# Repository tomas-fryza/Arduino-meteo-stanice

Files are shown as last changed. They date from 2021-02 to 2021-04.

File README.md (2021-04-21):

# Jednoduchá meteo stanice krok za krokem

Cílem tohoto projektu je seznámení s populární platformou Arduino, která obsahuje 8bitový mikrokontrolér AVR a je vhodná pro celou řadu řídicích aplikací. Bude vytvořen jednoduchý bod v síti Internet of Things, konkrétně meteo stanici se senzorem teploty a relativní vlhkosti vzduchu. Pro odesílání dat na server ThingSpeak je použita WiFi komunikace.

# Obsah
* [Použité komponenty](#Použité-komponenty)
* [Blokový diagram aplikace](#Blokový-diagram-aplikace)
* [Arduino Uno](#Arduino-Uno)
* [Sériová komunikace se senzorem a UART](#Sériová-komunikace-se-senzorem-a-UART)
  * [Sběrnice I2C](#Sběrnice-I2C)
  * [Asynchronní komunikace UART](#Asynchronní-komunikace-UART)
  * [Zobrazení dat ze senzoru v Serial monitoru](#Zobrazení-dat-ze-senzoru-v-Serial-monitoru)
* [WiFi komunikace](#WiFi-komunikace)
  * [Server ThingSpeak](#Server-ThingSpeak)
  * [Odeslání dat na server ThingSpeak](#Odeslání-dat-na-server-ThingSpeak)
* [Verze zdrojových kódů](#Verze-zdrojových-kódů)
* [Modifikace stanice](#Modifikace-stanice)
* [Kontakt](#Kontakt)

## Použité komponenty

* Vývojová deska [Arduino Uno](https://arduino-shop.cz/arduino/1353-klon-arduino-uno-r3-atmega328p-ch340-mini-usb-1466635561.html)
* I2C senzor vlhkosti a teploty DHT12 nebo [DHT11](https://dratek.cz/arduino/1360-dht11-dps-vodice-mereni-teploty-a-relativni-vlhkosti-modul-pro-arduino.html): [data sheet DHT12](Docs/dht12_manual.pdf), [návod DHT11](https://navody.dratek.cz/navody-k-produktum/teplotni-senzor-dht11.html)
* WiFi modul [ESP8266](https://dratek.cz/arduino/911-internet-veci-je-tady-tcp-ip-wifi-esp8266-esp-01.html): [AT příkazy](Docs/esp8266_at_instruction_set.pdf)
* [Nepájivé pole](https://dratek.cz/302-nepajive-pole/), propojující [vodiče](https://dratek.cz/arduino/827-vodice-samec-samec-65-kusu.html)
* Prostředí [Arduino IDE](https://www.arduino.cc/en/software) pro Windows, Linux, Mac OS X
* Server [ThingSpeak](https://thingspeak.com/)

Pro ověření komunikace je vhodnou komponentou také:
* 24MHz 8-kanálový [logický analyzátor](https://www.ebay.com/sch/i.html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)
* [Ovládací software](https://www.saleae.com/downloads/) logického analyzátoru pro Windows, Linux, Mac OS X

Obvodová schémata byla vytvořena v programu Fritzing 0.8.7b:
* Verze pro [Windows](http://fritzing.org/download/0.8.7b/windows/fritzing.0.8.7b.pc.zip)
* Verze pro [Linux](http://fritzing.org/download/0.8.7b/linux-32bit/fritzing-0.8.7b.linux.i386.tar.bz2)
* Verze pro [Mac OS](http://fritzing.org/download/0.8.7b/mac-os-x-105/fritzing.0.8.7b.cocoa.dmg)
* Model senzoru [DHT12](https://github.com/Bobadas/DHT12_library_Arduino/blob/master/DHT12%20Fritzing%20component.fzpz)
* Model WiFi modulu [ESP8266-01](https://github.com/ydonnelly/ESP8266_fritzing)

## Blokový diagram aplikace

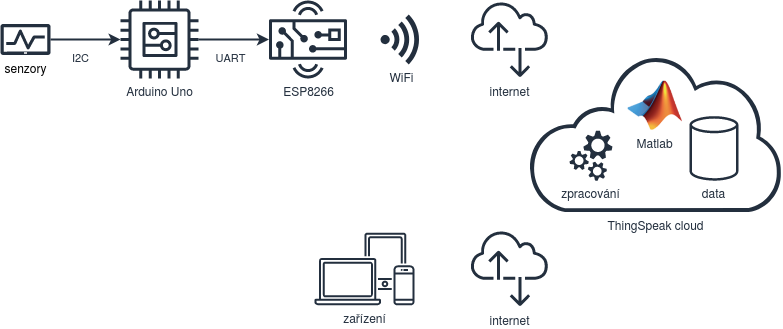
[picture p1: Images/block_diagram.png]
Blokový diagram


## Arduino Uno

Arduino je projekt vyvíjející otevřené platformy založené na 8bitovém mikrokontroléru s architekturou AVR (konkrétně [ATmega328P](https://www.microchip.com/wwwproducts/en/ATmega328P)). Podrobný popis HW modulů, včetně dostupných SW nástrojů, knihoven a manuálů naleznete na [webových stránkách](http://www.arduino.cc). Kromě originálu lze použít i levnější klony, které jsou plně kompatibilní.

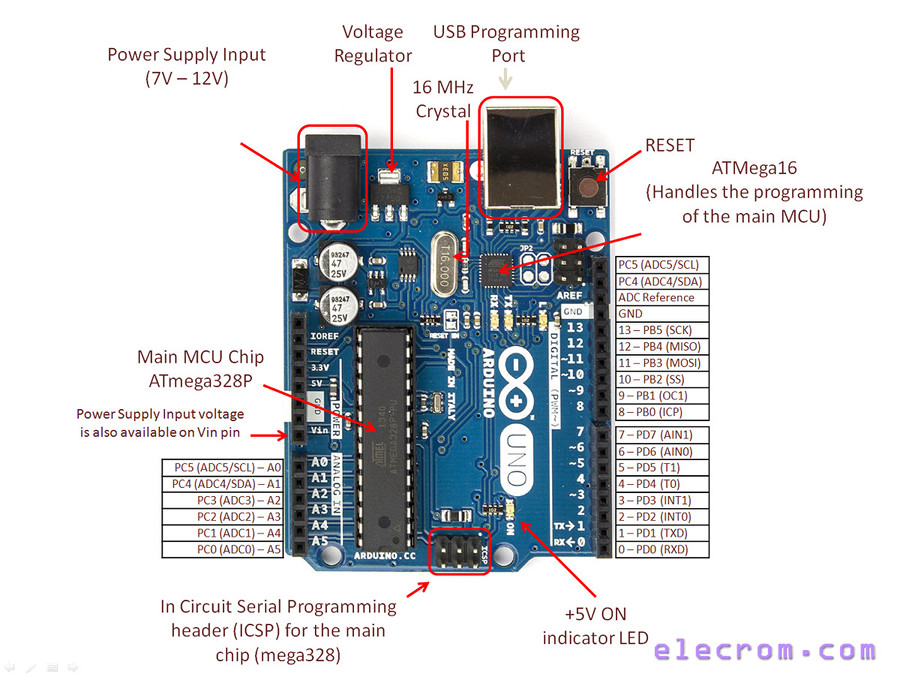
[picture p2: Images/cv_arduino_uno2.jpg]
Vývojová deska Arduino Uno


Řídicí program mikrokontroléru (tzv. firmware) je vyvíjen ve zjednodušené verzi jazyka C++ v prostředí [Arduino](https://www.arduino.cc/en/software), které je zdarma dostupné pro Windows, Mac OS X i Linuxové distribuce. Lze použít online verzi Arduino Web Editor (ke kterému je potřeba doinstalovat Arduino Create Agent pro programování hardwaru) nebo si stáhnout a lokálně nainstalovat prostředí Arduino IDE.

Toto prostředí je velmi jednoduché a kromě textového editoru nabízí jen několik ovládacích prvků. My využijeme pouze: **Verify** pro přeložení zdrojového kódu, **Upload** pro nahrání binární verze kódu do vývojové desky a **Serial Monitor** k otevření nového okna s asynchronní komunikaci mezi mikrokontrolérem a počítačem po USB kabelu.

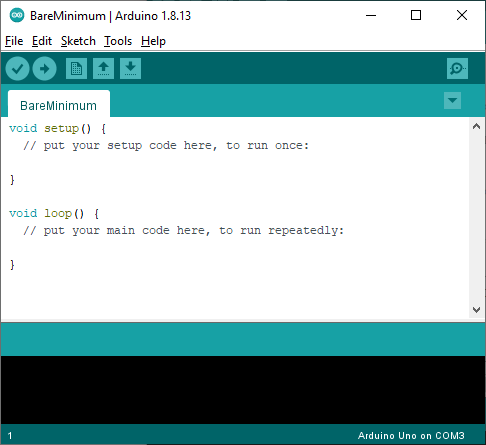
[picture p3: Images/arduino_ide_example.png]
Vývojové prostředí Arduino IDE


## Sériová komunikace se senzorem a UART

### Sběrnice I2C

Pomocí nepájivého pole a vodičů připojte na datový (SDA) a hodinový (SCL) signál sběrnice I2C modul pro měření teploty/vlhkosti DHT12. Pro napájení použijte napětí 3.3 V a GND z vývojové desky Arduina.

   | **DHT12** | **Arduino Uno** |
   | :-: | :-: |
   | + | 3.3V |
   | SDA | SDA |
   | - | GND |
   | SCL | SCL |

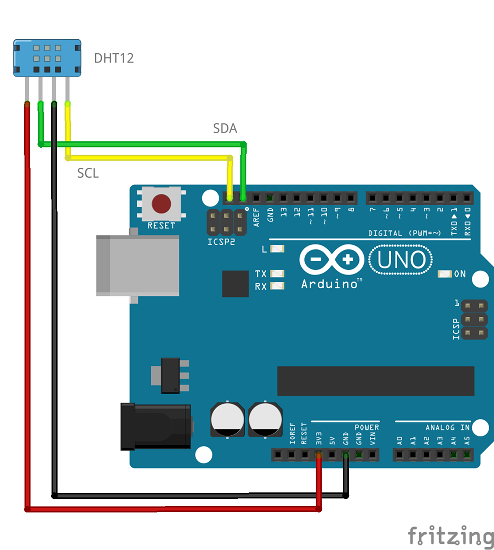
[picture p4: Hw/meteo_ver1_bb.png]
Zapojení senzoru DHT12


Kombinované čidlo komunikuje po digitální sériové sběrnici I2C (Inter-integrated Circuit). Ta obsahuje dva vodiče: pro přenos dat s označením SDA a pro přenos hodinových impulzů SCL a umožňuje snadné propojení jednoho nadřízeného obvodu (tzv. master) s více podřízenými obvody (slave). Jako master je použit mikrokontrolér AVR na vývojové desce Arduino Uno a slave obvod je čidlo teploty/vlhkosti DHT12 (lze ale připojit desítky dalších slave obvodů).

Při komunikaci na sběrnici I2C se nejprve adresuje podřízený obvod jediněčnou adresou, která je zadaná od výrobce (pro obvod DHT12 je to adresa 184 pro zápis a 185 pro čtení). Následně může proběhnout výměna dat jedním nebo druhým směrem.

Vnitřní uložení dat v senzoru DHT12:

   | **Adresa registru** | **Popis** |
   | :-: | :-- |
   | 0 | Celočíselná část vlhkosti |
   | 1 | Desetinná část vlhkosti |
   | 2 | Celočíselná část teploty |
   | 3 | Desetinná část teploty |
   | 4 | Kontrolní součet |

Hodnota relativní vlhkosti vzduchu i teploty se skládá z celočíselné a desetinné části. Pro zjištění obou veličin je tak potřebné přijmout ze senzoru 4 datové byty uložené na vnitřní adrese 0 až 3. Ukázka sériové komunikace I2C pomocí logického analyzátoru; konkrétně byla přenesena hodnota vlhkosti `24.0`% a teploty `22.4` stupňů Celsia:

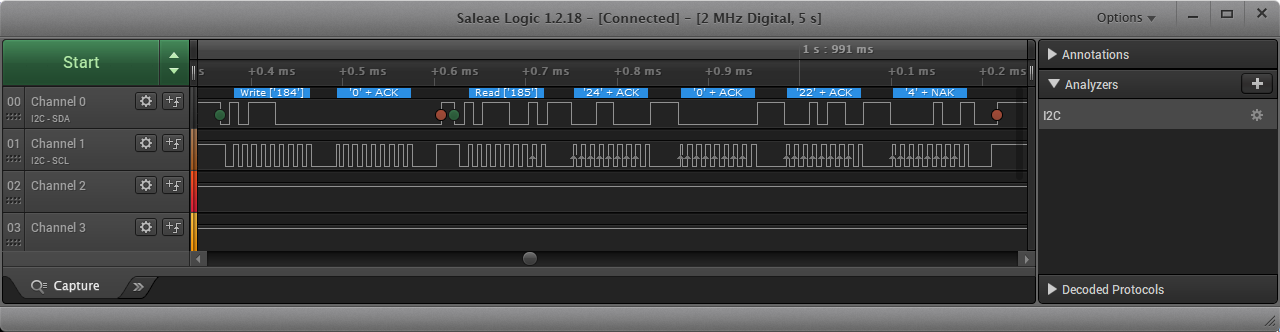
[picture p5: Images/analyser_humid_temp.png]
I2C komunikace se senzorem


Pro ovládání komunikace I2C jsou využity funkce z knihovny [`Wire.h`](https://www.arduino.cc/en/reference/wire). Detailnější informace o sériové komunikaci I2C je možné nalézt v materiálech předmětu [Digitální elektronika 2](https://github.com/tomas-fryza/Digital-electronics-2/tree/master/Labs/08-i2c).

### Asynchronní komunikace UART

Jednotka UART (Universal Asynchronous Receiver Transmiter) umožňuje převádět paralelní data na sériová a opačně. Obsahuje vysílací signál Tx i přijímací Rx a rychlost komunikace se udává v Bd (bódech). Typickou hodnotou je např. 9600 Bd.

Užitečná data jsou zabalena do komunikačního rámce, který začíná start bitem, následuje pět až devět datových bitů seřazených od LSB k MSB, může být použit paritní bit pro základní ověření korektního příjmu (sudá nebo lichá). Komunikace je zakončena jedním nebo dvěma stop bity. Struktura rámce musí být dopředu domluvena a označuje se symbolicky: 7E2 (sedm datových bitů, sudá parita, dva stop bity), 8N1 (osm dat, bez parity, jeden stop), apod.

Ukázka UART komunikace v módu 8N1 pomocí logického analyzátoru:

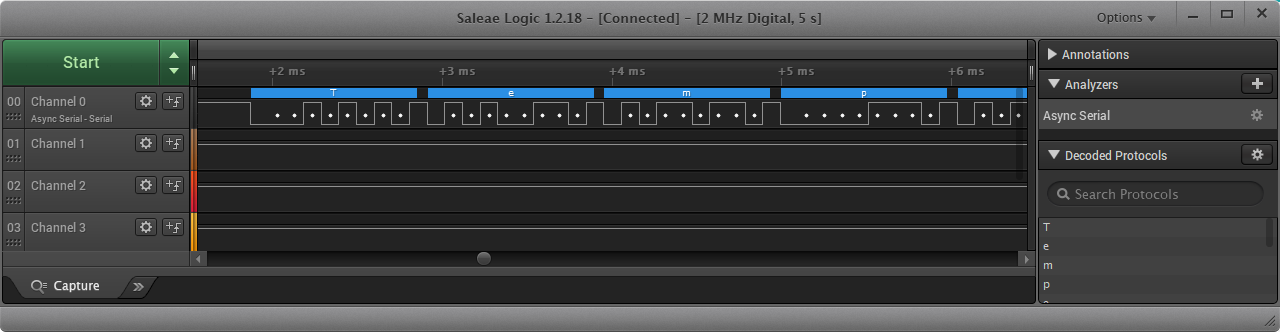
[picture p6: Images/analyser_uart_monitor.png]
Přenos AT příkazu pomocí UART


Pro ovládání sériové komunikace UART jsou využity interní funkce Arduina [`Serial`](https://www.arduino.cc/reference/en/language/functions/communication/serial/). Detailnější informace o sériové komunikaci UART je možné nalézt v materiálech předmětu [Digitální elektronika 2](https://github.com/tomas-fryza/Digital-electronics-2/tree/master/Labs/07-uart).

### Zobrazení dat ze senzoru v Serial monitoru

Zdrojový kód aplikace pro čtení dat ze senzoru a jejich zobrazení v **Sériovém monitoru** překopírujte z [meteo_ver1](https://github.com/tomas-fryza/Arduino-meteo-stanice/blob/main/Arduino/meteo_ver1/meteo_ver1.ino) do Arduino IDE, zkompilujte jej a nahrajte do vývojové desky. Otevřete sériový monitor a nastavte v něm stejnou symbolovou rychlost s jakou mikrokontrolér data vysílá, tj. 9600 baud.

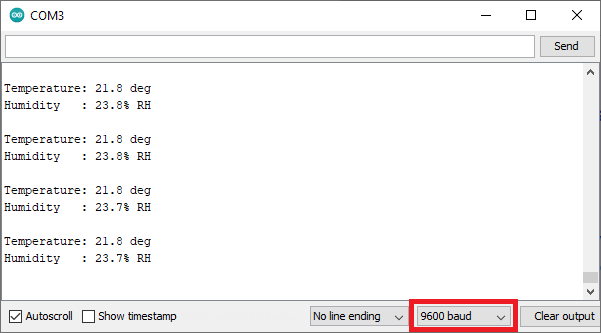
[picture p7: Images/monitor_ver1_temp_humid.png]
Serial monitor


## WiFi komunikace

Komunikační modul ESP8266 umožňuje využít bezdrátovou síť WiFi, připojit se k ní a odesílat data na server. Ovládání modulu probíhá prostřednictvím tzv. [AT příkazu](Docs/esp8266_at_instruction_set.pdf) což jsou textové řetězce začínající znaky `AT` a pokračující příkazem z manuálu.

Pomocí nepájivého pole a vodičů připojte WiFi modul ESP8266 ESP-01 a Arduino Uno dle tabulky. Výměna dat mezi modulem a řídicím mikrokontrolérem probíhá prostřednictvím asynchronní komunikace. Všimněte si, že vysílací pin modulu je proto spojen s přijímacím pinem Arduino a obráceně.

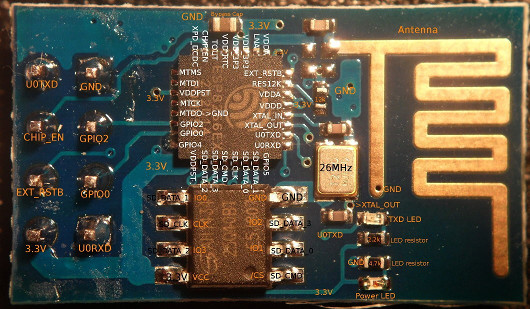
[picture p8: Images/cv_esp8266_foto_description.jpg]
Připojení modulu ESP8266


   | **ESP8266** | **Arduino Uno** |
   | :-: | :-: |
   | U0TXD | Rx (pin 0) |
   | CHIP_EN | 3.3V |
   | EXT_RSTB | Nepřipojeno |
   | 3.3V | 3.3V |
   | GND | GND |
   | GPIO2 | Nepřipojeno |
   | GPIO0 | Nepřipojeno |
   | U0RXD | Tx (pin 1) |

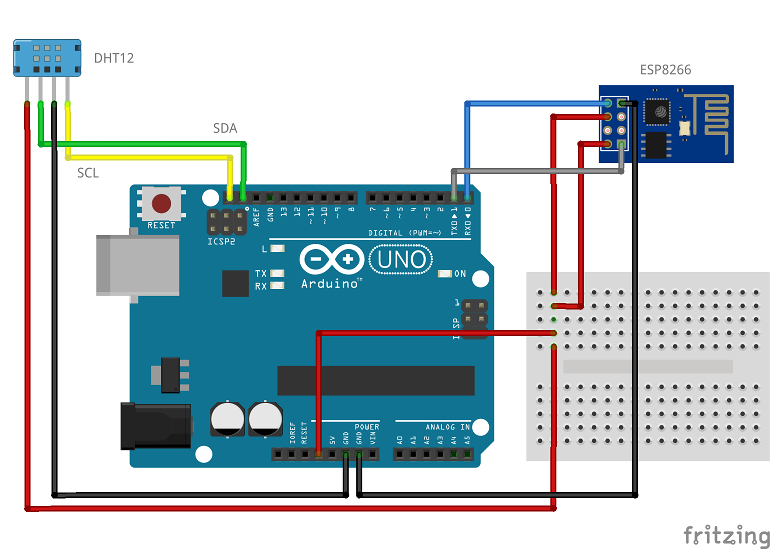
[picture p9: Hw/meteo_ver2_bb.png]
Zapojení modulu ESP8266


### Server ThingSpeak

Pro vytvoření komunikačního kanálu pro sběr dat z vašeho senzoru postupujte podle následujících kroků:

1. V prohlížeči otevřete stránku https://thingspeak.com/ a stiskněte tlačítko **Get Started For Free**.

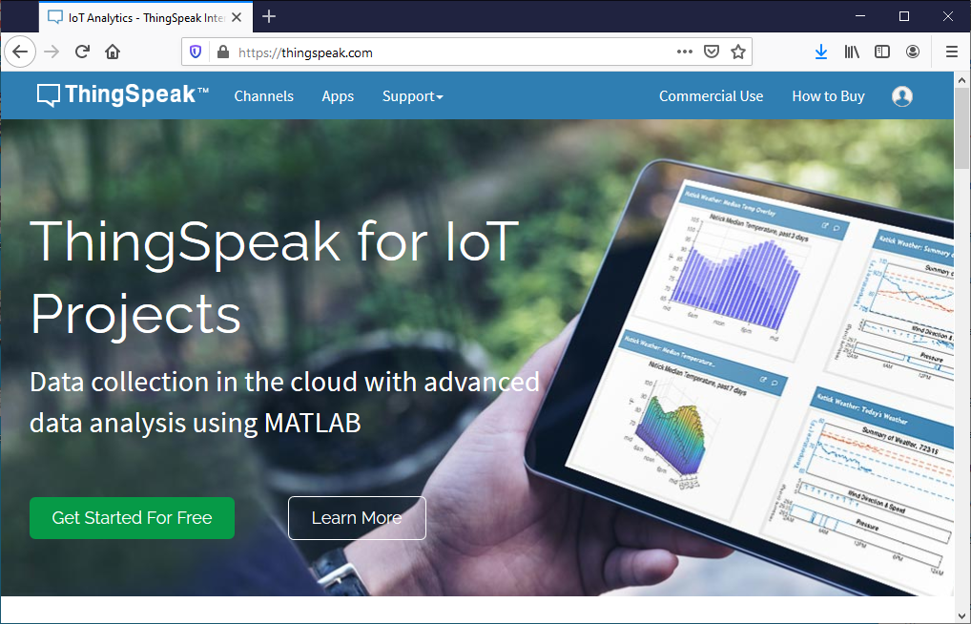
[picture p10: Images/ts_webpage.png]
Web ThingSpeak
   

2. Vytvořte si účet--který je zdarma--pomocí vašeho emailu. Žádnou reklamu na email nerozesílají. Po vytvoření se do systému nalogujte.
3. Vytvořte nový komunikační kanál tlačítkem **New Channel**. Seznam kanálů naleznete kdykoliv v menu **Channels > My Channels**.
4. Vyplňte jméno kanálu, jeho případný popis a vyberte kolik hodnot budete v kanálu posílat. V části **Tags** můžete uvést klíčová slova, podle kterých bude váš kanál lépe dosažitelný. Vše uložte tlačítkem **Save Channel**.

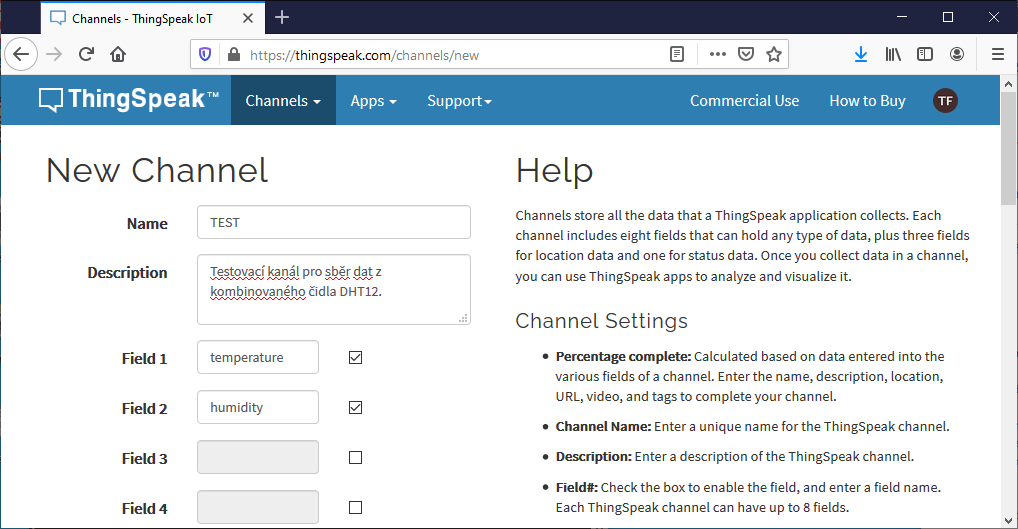
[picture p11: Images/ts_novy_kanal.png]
Tvorba nového kanálu
   

5. Nastavení kanálu můžete kdykoliv změnit a doplnit v záložce **Channel Settings**. Volbou **Sharing** lze nastavit, zda vaše data budou dostupná všem, nebo jen vám po nalogování. V záložce **API Keys** naleznete identifikátory, které byly pro váš kanál vygenerovány a jsou jeho jedinečným označením. V naší aplikaci budeme na server pouze zapisovat a budeme tak potřebovat pouze **Write API Key**, který později vložíme do zdrojového kódu aplikace.

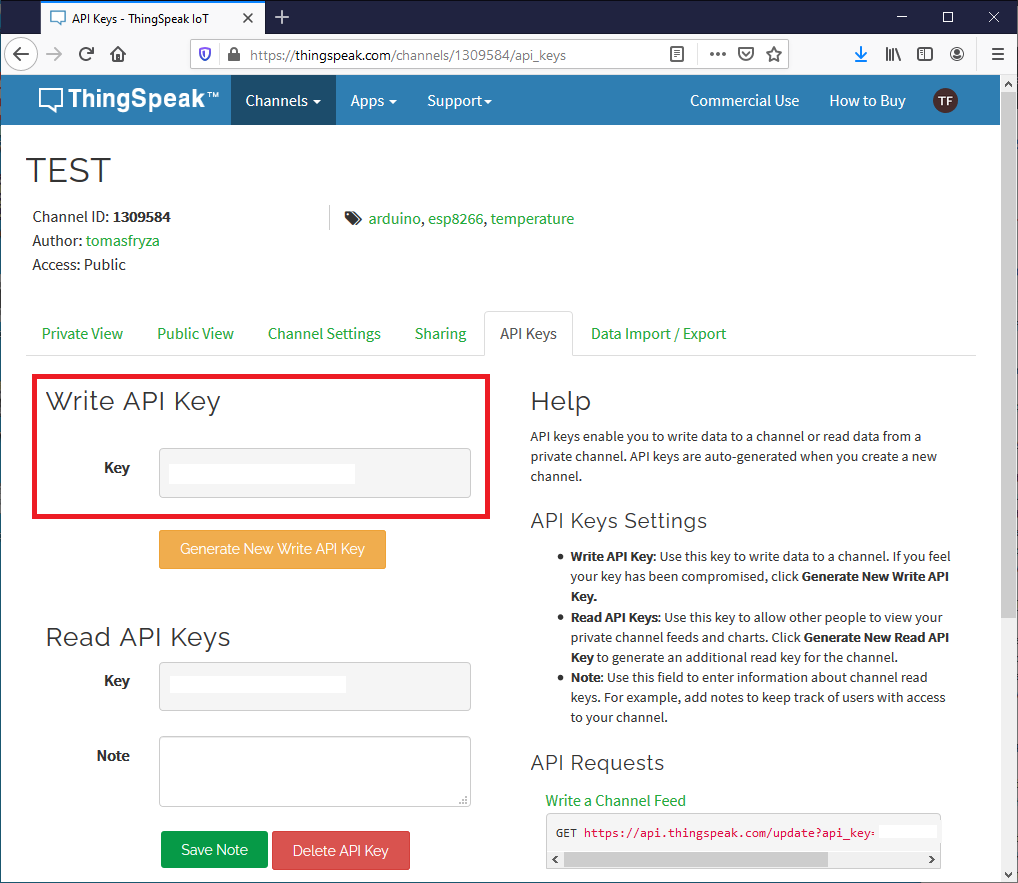
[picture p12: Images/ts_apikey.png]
Write API Key
   

6. Data je možné zobrazit odděleně pro vás (**Private View**) nebo pro všechny ostatní (**Public View**).

### Odeslání dat na server ThingSpeak

Použijte zdrojový kód [meteo_ver2](https://github.com/tomas-fryza/Arduino-meteo-stanice/blob/main/Arduino/meteo_ver2/meteo_ver2.ino) a překopírujte jej do prostředí Arduino IDE. Do kódu doplňte informace o vaší WiFi síti a APIWrite kód z předchozího bodu.

```c
// ENTER YOUR VALUES
String ssid        = "xxx"; // SSID of your WiFi network
String password    = "xxx"; // Password of your WiFi network
String writeApiKey = "xxx"; // Write API Key from ThingSpeak cloud
```

Kód přeložte a nahrajte do Arduino Uno. Vzhledem k tomu, že programování Arduina probíhá na stejných pinech, kde je připojen i WiFi modul, před samotným uploadem kódu odpojte vodiče z pinů 0 a 1 (Rx a Tx). Po úspěšném naprogramování vodiče opět připojte. Spusťte **Serial Monitor** na kterém pozorujte část komunikace s WiFi modulem (pozor, odpovědi modulu se nezobrazují a je nutné nastavit rychlost komunikace na 115200 baud):

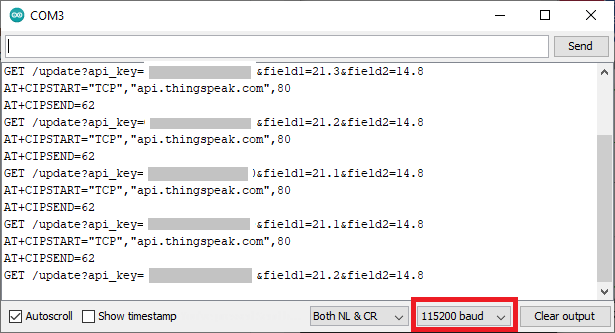
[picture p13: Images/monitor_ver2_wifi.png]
Serial monitor


Je-li komunikace prostřednictvím WiFi sítě korektní, na webové stránce `thingspeak.com` se začnou shromažďovat a zobrazovat změřená data. Pokud tomu tak není, zkontrolujte zadané údaje v kódu, případně si zobrazte asynchronní komunikaci na pinech 0 a 1 pomocí logického analyzátoru.

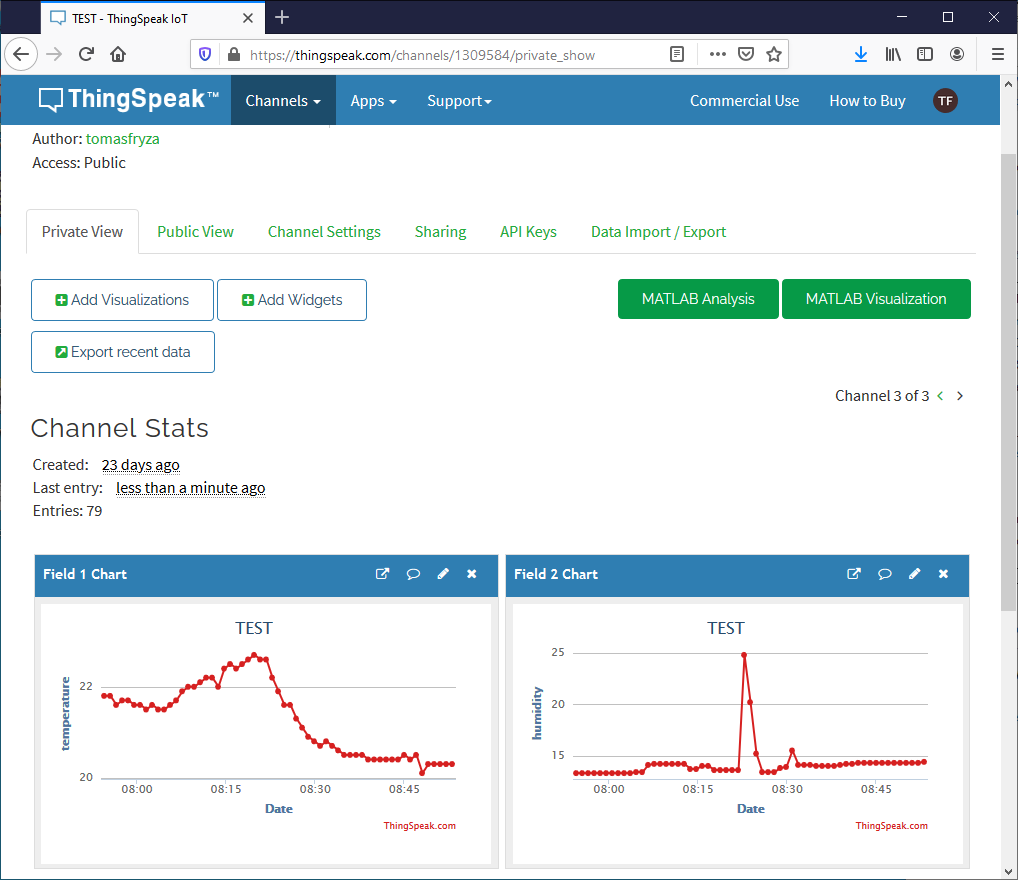
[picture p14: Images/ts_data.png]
Sběr dat na ThingSpeak


## Verze zdrojových kódů

   | **Číslo verze** | **Popis** |
   | :-: | :-- |
   | [ver0](Arduino/meteo_ver0/meteo_ver0.ino) | Skener zařízení připojených na sběrnici I2C |
   | [ver1](Arduino/meteo_ver1/meteo_ver1.ino) | Čtení teploty + vlhkosti z DHT12 a zobrazení v Serial monitoru |
   | [ver2](Arduino/meteo_ver2/meteo_ver2.ino) | Čtení hodnot z DHT12 a odeslání pomocí ESP8266 na ThingSpeak |
   | [ver3](Arduino/meteo_ver3/meteo_ver3.ino) | Komunikace s WiFi modulem ESP8266 pomocí softwarového UARTu  |

## Modifikace stanice

Rozšířit tuto základí aplikaci lze celou řadou modulů a senzorů, např. tlak vzduchu, míra osvětlení, senzor srážek, síla větru, vlhkost půdy, aj. Velký výběr naleznete např. na serveru [dratek.cz](https://dratek.cz/).

Vladimír Lahoda. [Automatizovaný měřící systém pro zavlažování rostlin s IoT konektivitou](https://www.facebook.com/URELBrno/posts/1459331204276701). Bakalářská práce v programu BPC-EKT, červen 2020. Klíčová slova: LoRa, ESP32, Embedded, Meteostanice, Zavlažování.

## Q & A

Q: Kolik dat lze do jednoho kanálu ThingSpeak odeslat?

Q: Jaký je celkový datový tok?

## Kontakt

<!-- Please don't remove this: Grab your social icons from https://github.com/carlsednaoui/gitsocial -->
<!-- display the social media buttons in your README -->



[][2]
[][6]

<!-- links to social media icons -->
<!-- no need to change these -->

<!-- icons with padding -->

[1.1]: http://i.imgur.com/tXSoThF.png (twitter icon with padding)
[2.1]: http://i.imgur.com/P3YfQoD.png (facebook icon with padding)
[3.1]: http://i.imgur.com/yCsTjba.png (google plus icon with padding)
[4.1]: http://i.imgur.com/YckIOms.png (tumblr icon with padding)
[5.1]: http://i.imgur.com/1AGmwO3.png (dribbble icon with padding)
[6.1]: http://i.imgur.com/0o48UoR.png (github icon with padding)

<!-- icons without padding -->

[1.2]: http://i.imgur.com/wWzX9uB.png (twitter icon without padding)
[2.2]: http://i.imgur.com/fep1WsG.png (facebook icon without padding)
[3.2]: http://i.imgur.com/VlgBKQ9.png (google plus icon without padding)
[4.2]: http://i.imgur.com/jDRp47c.png (tumblr icon without padding)
[5.2]: http://i.imgur.com/Vvy3Kru.png (dribbble icon without padding)
[6.2]: http://i.imgur.com/9I6NRUm.png (github icon without padding)

<!-- links to your social media accounts -->
<!-- update these accordingly -->

[1]: http://www.twitter.com/carlsednaoui
[2]: https://www.facebook.com/URELBrno
[3]: https://plus.google.com/+CarlSednaoui
[4]: http://carlsed.tumblr.com
[5]: http://dribbble.com/carlsednaoui
[6]: http://www.github.com/tomas-fryza

<!-- Please don't remove this: Grab your social icons from https://github.com/carlsednaoui/gitsocial -->

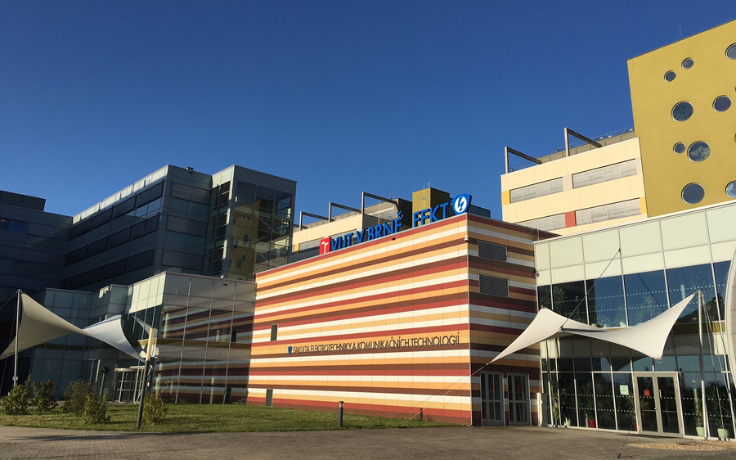
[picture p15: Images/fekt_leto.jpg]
Foto fakulty FEKT


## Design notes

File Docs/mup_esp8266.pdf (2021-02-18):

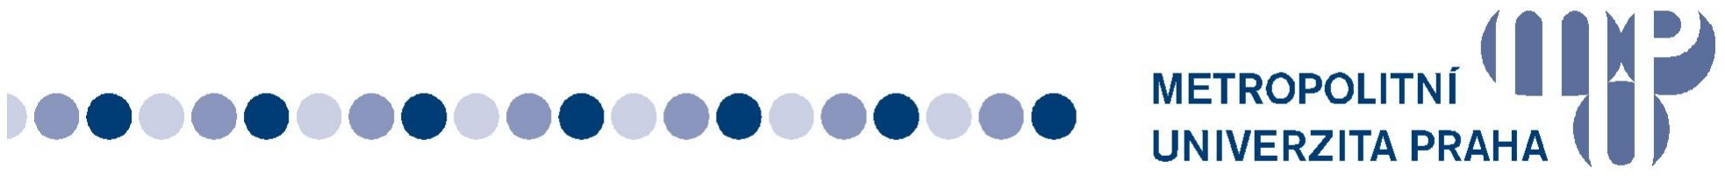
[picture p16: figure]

# Technologicko-experimentální praxe

## Arduino (duben 2018)

doc. Ing. Tomáš Frýza, Ph.D.

Metropolitní univerzita Praha | 1

## Obsah

1 Základní použití platformy Arduino | 4
2 Rízení sériové komunikace I2C ˇ | 11
3 Komunikace s WiFi modulem | 17

2 | Technologicko-experimentální praxe

## Seznam obrázků

1.1 Vývojová deska Arduino Uno | | 4
1.2 Vývojové prostředí Arduino IDE s příkladem Blink | | 5
1.3 Casový průběh signálu LED diody ˇ | | | 6
1.4 Zapojení druhé LED diody prostřednictvím nepájivého pole | | 7
1.5 Průběh časového signálu asynchronní komunikace s dekódovanými daty | | 9
2.1 Zachycení sériové komunikace na sběrnici I2C | | 14
3.1 Označení pinů na modulu ESP8266 ESP-01 | | 18
3.2 Vizualizace měřených dat na serveru https://thingspeak.com/ | | 21

## Seznam tabulek

2.1 Uložení dat v kombinovaném senzoru DHT12 | | 12
2.2 Uložení dat v obvodu reálného času RTC DS3231 | | 14

## 1 Základní použití platformy Arduino

Cílem tohoto cvičení je seznámení s populární platformou Arduino, která obsahuje 8bitový mikrokontrolér AVR a je vhodná pro celou řadu řídicích aplikací. Aplikace budou programovány v jazyce C++ v prostředí Arduino IDE, které je zdarma dostupné pro Windows, Mac OS X i Linux. Pro verifikaci správné funkce aplikací bude použit logický analyzátor firmy Seleae, Inc.

### 1.1 Arduino Uno

Arduino je projekt vyvíjející otevřené platformy založené na 8bitovém mikrokontroléru s architekturou AVR. Podrobný popis HW modulů, včetně dostupných SW nástrojů, knihoven a manuálů naleznete na webových stránkách http://www.arduino.cc. Ve cvičení je využívána základní vývojová deska Arduino Uno, resp. její levnější, ale plně kompatibilní čínský klon.

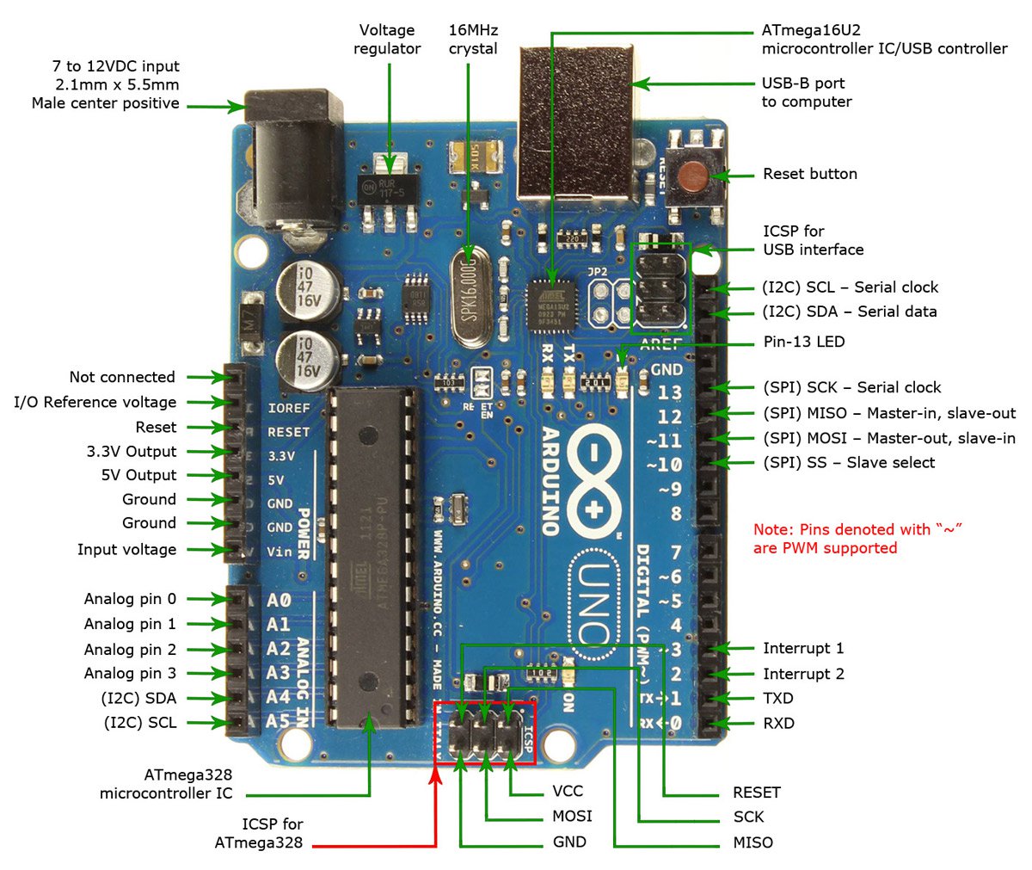
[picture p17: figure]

Obrázek 1.1: Vývojová deska Arduino Uno

Vývojové prostředí Arduino IDE je velmi jednoduché a kromě textového editoru nabízí několik ovládacích prvků. My využijeme pouze: Verify (Compile) pro přeložení zdrojového kódu, Upload pro nahrání binární verze kódu do vývojové desky a Serial Monitor k otevření nového okna s asynchronní komunikaci mezi mikrokontrolérem a počítačem po USB kabelu.

Příklad 1.1. Naprogramujte aplikaci pro blikání jedné LED diody.

Rešení 1.1. ˇ | Prostředí obsahuje také základní sadu příkladů. V menu File / Examples /
01.Basics vyberte příklad Blink. Příklad se ovevře v novém okně, viz obrázek 1.2.
| Zdrojové kódy pro Arduino svou strukturou usnadňují vývoj aplikací i méně zkušeným pro-
gramátorům. Standardně obsahují dvě funkce: setup(), která se spustí jedenkrát po resetu mikrokontroléru a loop(), která představuje nekonečnou smyčku hlavní aplikace a neustále se opakuje.

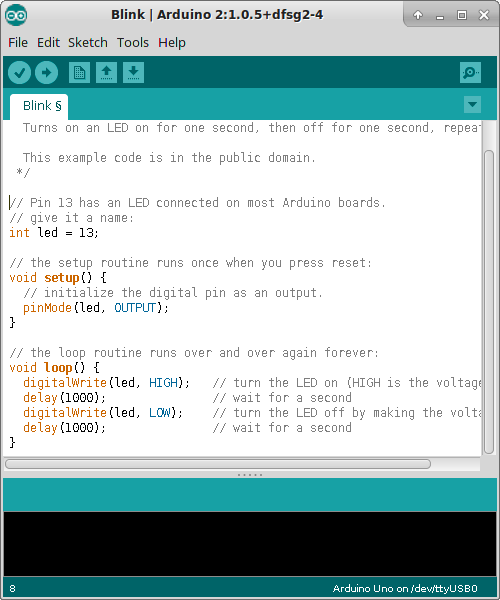
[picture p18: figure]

Obrázek 1.2: Vývojové prostředí Arduino IDE s příkladem Blink

V aplikaci je použita globální proměnná led = 13, která specifikuje jeden konkrétní pin mikrokontroléru. Právě na pinu číslo 13 je na Arduino Uno připojena LED dioda. Dále příklad volá jen tři funkce: pinMode(), pomocí které se konfiguruje náš pin jako výstupní, digitalWrite() je funkce pro nastavení vysoké nebo nízké napět’ové úrovně na výstupním pinu a delay(), která pozdrží výkon programu na stanovený počet milisekund.

// Pin 13 has an LED connected on most Arduino boards. // give it a name:
int led = 1 3;

// the setup routine runs once when you press reset: void setup ( ) {
// initialize the digital pin as an output. pinMode ( led , OUTPUT ) ;
}

// the loop routine runs over and over again forever:
void loop ( ) {
digitalWrite ( led , HIGH ) ; | // turn the LED on (HIGH is the voltage level)
delay ( 1 0 0 0 ) ; | // wait for a second
digitalWrite ( led , LOW ) ; | // turn the LED off by making the voltage LOW
delay ( 1 0 0 0 ) ; | // wait for a second
}

Otestujte si svůj zrak a postupně snižujte hodnotu zpoždění až nebude pro vás blikání LED na desce pozorovatelné.

Příklad 1.2. Ověřte dobu zpoždění pomocí logického analyzátoru.

Rešení 1.2. ˇ | Alogický analyzátor je HW zařízení, které je schopné převádět reálné signály do
číslicové podoby a zobrazovat jejich časové průběhy. Ve cvičení bude využit levný klon analyzátoru firmy Saelea, Inc., jehož ovládací a zobrazovací software je zdarma stažitelný z webových stránek https://www.saleae.com/downloads pro libovolnou platformu.
| Pomocí dvou vodičů připojte GND vstup analyzátoru s GND pinem na Arduino desce a vstup
CH1 s pinem 13. Spust’te aplikaci analyzátoru Logic a s pomocí zeleného tlačítka se dvěma šipkami nastavte dobu snímání vstupního signálu Duration (Record data for) na 100 milisekund a rychlost vzorkování Speed (Sample Rate) na 1 MS/s. Tlačítkem Start spustíte vzorkování (záznam) signálu pro LED diodu na pinu 13. Ověřte správnost časování generovaného signálu pro odlišné hodnoty zpoždění funkce delay().

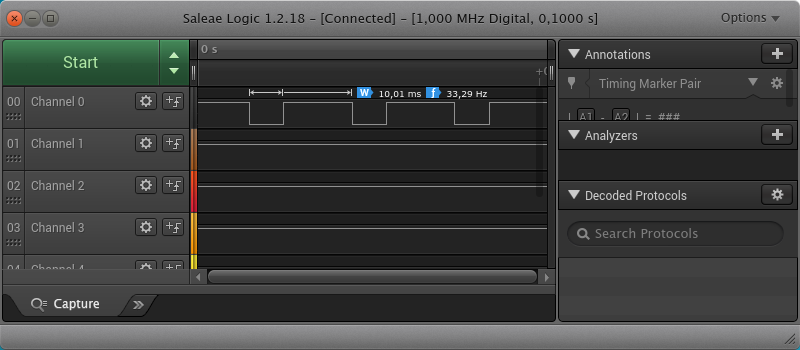
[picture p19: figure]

Obrázek 1.3: Casový průběh signálu LED diody. (Doba zpoždění HIGH zde nastavena na 20 ˇ a LOW na 10 ms.)

Příklad 1.3. Přidejte do aplikace druhou LED a zajistěte, aby blikaly střídavě.

Rešení 1.3. ˇ | Pomocí nepájivého pole zapojte druhou LED diodu a rezistor omezující elektrický
proud jí tekoucí mezi pin 12 a napájecí napětí 5 V dle obrázku 1.4. Do zdrojového kódu přidejte řádky ovládající výstupní pin 12. Celá aplikace může vypadat dle následujícího výpisu.

// Pin 13 has an LED connected on most Arduino boards.
// give it a name:
int led = 1 3;
int led2 = 1 2;

// the setup routine runs once when you press reset: void setup ( ) {
// initialize the digital pin as an output. pinMode ( led , OUTPUT ) ;
pinMode ( led2 , OUTPUT ) ;
}

// the loop routine runs over and over again forever:
void loop ( ) {
digitalWrite ( led , HIGH ) ; // turn the LED on (HIGH is the voltage level)

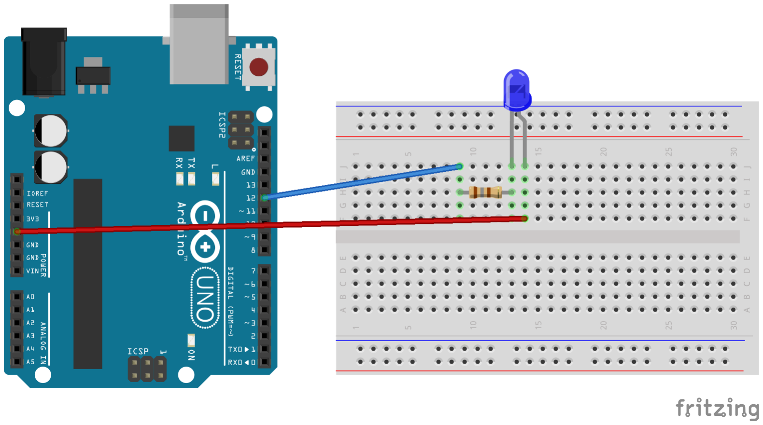
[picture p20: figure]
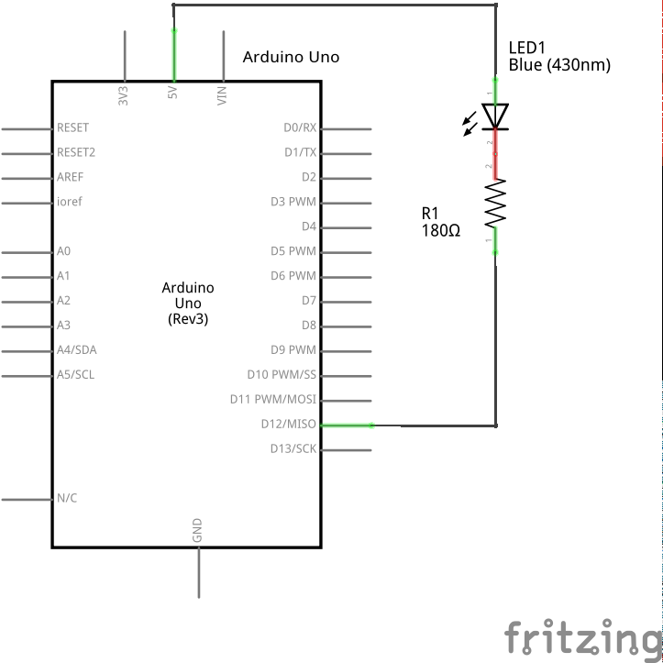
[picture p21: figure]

Obrázek 1.4: Zapojení druhé LED diody prostřednictvím nepájivého pole

digitalWrite ( led2 , HIGH ) ; | // turn the LED on (HIGH is the voltage level)
delay ( 2 5 0 ) ; | // wait for a second
digitalWrite ( led , LOW ) ; | // turn the LED off by making the voltage LOW
digitalWrite ( led2 , LOW ) ; | // turn the LED off by making the voltage LOW
delay ( 5 0 0 ) ; | // wait for a second
}

Všimněte si, že obě LED diody svítí při odlišných úrovních signálů na pinech 12 a 13. Je to dáno orientací LED diod: zelená LED na vývojové desce je připojena anodou na pin 13 a katodou na GND, zatímco LED na nepájivém poli má anodu na +5 V a katodu na řídicí pin 12.

### 1.2 Asynchronní komunikace

Příklad 1.4. Vytvořte aplikaci vysílající asynchronní data z Arduina do počítače.

Rešení | 1.4. ˇ | Otevřete | si | příklad | z | menu | File / Examples / 04.Communication /
ASCIITable využívající asynchronní jednosměrné komunikace od vývojové desky do počítače. Po překompilování kódu a nahrání do mikrokontroléru na desce, spust’te také Serial Monitor (ikona vpravo nahoře). Do nově otevřeného okna se postupně vypíší zobrazitelné znaky z ASCII tabulky a jejich kódy v desítkové, šestnáctkové, osmičkové a binární soustavě.
V aplikaci jsou využity funkce pro konfiguraci vysílače sériových dat begin(9600) se symbolovou rychlostí 9 600 Bd, dále dvě funkce pro vysílání textových řetězců po asynchronní sériové lince println() a print() a vyslání jednoho sériového rámce funkcí write(). S pomocí manuálu na webových stránkách https://www.arduino.cc/reference/en/language/functions/communication/serial/ (https://www.arduino.cc/reference/en/language/functions/communication/serial/) příp. experimentálně zjistěte význam těchto funkcí.

void setup ( ) {
// Initialize serial and wait for port to open:
Serial . begin ( 9 6 0 0 ) ;
while ( ! Serial ) {
; // wait for serial port to connect. Needed for Leonardo only
}

// prints title with ending line break
Serial . println ( "ASCII Table ~ Character Map" ) ;
}

// first visible ASCIIcharacter '!' is number 33:

int thisByte = 3 3;
// you can also write ASCII characters in single quotes.
// for example. '!' is the same as 33 , so you could also use this: //int thisByte = '!';

void loop ( ) {
// prints value unaltered , i.e. the raw binary version of the // byte. The serial monitor interprets all bytes as
// ASCII , so 33 , the first number , will show up as '!' Serial . write ( thisByte ) ;

Serial . print ( ", dec: " ) ;
// prints value as string as an ASCII -encoded decimal (base 10).
// Decimal is the default format for Serial.print () and Serial.println (), // so no modifier is needed:
Serial . print ( thisByte ) ;
// But you can declare the modifier for decimal if you want to.
// this also works if you uncomment it:

// Serial.print(thisByte , DEC);

Serial . print ( ", hex: " ) ;
// prints value as string in hexadecimal (base 16): Serial . print ( thisByte , HEX ) ;

Serial . print ( ", oct: " ) ;
// prints value as string in octal (base 8); Serial . print ( thisByte , OCT ) ;

Serial . print ( ", bin: " ) ;
// prints value as string in binary (base 2) // also prints ending line break:
Serial . println ( thisByte , BIN ) ;

// if printed last visible character '~' or 126 , stop:
if ( thisByte == 1 2 6 ) { | // you could also use if (thisByte == '~') {
// This loop loops forever and does nothing
while ( true ) {
continue ;
}
}
// go on to the next character thisByte++;
}

Příklad 1.5. Ověřte strukturu asynchronních rámců.

Rešení 1.5. ˇ | Ukázkový kód z předchozího příkladu zjednodušte na vyslání krátkého řetězce
a logickým analyzátorem připojeným na pin TX->1 zachyt’te časový průběh takovéto komunikace. Ověřte, že (a) komunikace se zahajuje start bitem, (b) počet datových bitů je osm a jsou seřazeny od LSB k MSB, (c) není použita žádná parita a (d) počet stop bitů je jeden.

void setup ( ) {
// Initialize serial and wait for port to open:
| Serial . begin ( 9 6 0 0 ) ; while ( ! Serial ) { ; // wait for serial port to connect. Needed for Leonardo only

}
}

void loop ( ) {
Serial . println ( "Hi" ) ; delay ( 1 0 0 ) ;
}

Logický analyzátor lze také nastavit pro přehlednější dekódování sériových dat. Stiskněte tlačítko ”+”v části Analyzers a vyberte typ komunikace Async Serial. Ponechte defaultní nastavení komunikačního rámce a stiskněte tlačítko Save. Do časového průběhu se zobrazí dekódované hodnoty jednotlivých komunikačních rámců.

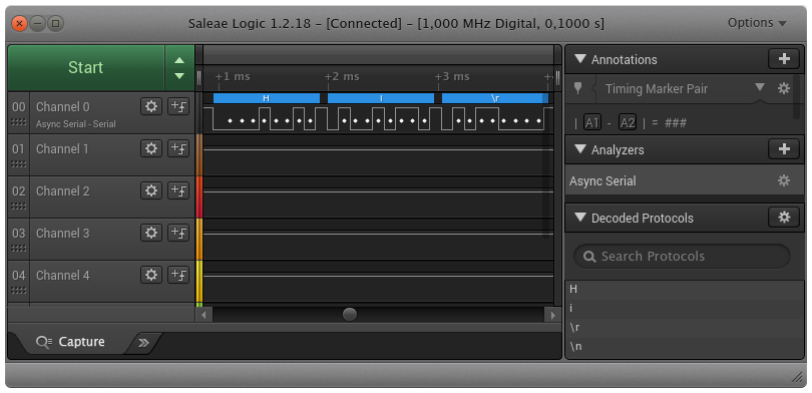
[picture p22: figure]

Obrázek 1.5: Průběh časového signálu asynchronní komunikace s dekódovanými daty

S pomocí analyzátoru experimentálně zjistěte rozdíl v použití vysílacích funkcí print() a println().

Příklad 1.6. Vytvořte aplikaci kombinující vysílač i přijímač asynchronních dat.

Rešení 1.6. ˇ | Kombinací kódů s LED diodou a vysílače sériových dat vznikne následující apli-
kace. V nekonečné smyčce je navíc volána funkce parseInt(), která reprezentuje přijímač sériových dat a plní globální proměnnou delayParam (popis celé funkce viz https://www.arduino.cc/reference/en/language/functions/communication/serial/parseint/). Tato proměnná udává dobu zpoždění pro blikání LED diodou.

// Pin 13 has an LED connected on most Arduino boards. // give it a name:
int led = 1 3;
int delayParam = 1 0 0 0;

// the setup routine runs once when you press reset: void setup ( ) {
| // initialize the digital pin as an output. pinMode ( led , OUTPUT ) ;

// Initialize serial and wait for port to open:
| Serial . begin ( 9 6 0 0 ) ; while ( ! Serial ) {

; // wait for serial port to connect. Needed for Leonardo only
}
}

// the loop routine runs over and over again forever: void loop ( ) {
// check if data has been sent from the computer: if ( Serial . available ( ) ) {
// read the most recent integer:
delayParam = Serial . parseInt ( ) ;
}

digitalWrite ( led , HIGH ) ; // turn the LED on (HIGH is the voltage level) Serial . println ( "HIGH" ) ;
Serial . println ( delayParam ) ;
delay ( delayParam ) ; | // wait for a second
digitalWrite ( led , LOW ) ; | // turn the LED off by making the voltage LOW
Serial . println ( "LOW" ) ;
delay ( delayParam ) ; | // wait for a second
}

## 2 Rízení sériové komunikace I2C ˇ

Cílem tohoto cvičení je seznámení se sériovou sběrnicí I2C (Inter-integrated Circuit). Sériová sběrnice obsahuje dva vodiče: pro přenos dat s označením SDA a pro přenos hodinových impulzů SCL a umožňuje snadné propojení jednoho nadřízeného obvodu (tzv. master) s více podřízenými obvody (slave). Jako master je použit mikrokontrolér AVR na vývojové desce Arduino Uno a slave obvody jsou kombinované teplotní a vlhkostní čidlo DHT12 a obvod reálného času DS3231. Aplikace budou programovány v jazyce C++ v prostředí Arduino IDE. Pro verifikaci správné funkce aplikací bude použit logický analyzátor firmy Saleae, Inc.

Příklad 2.1. Naprogramujte aplikaci pro skenování sběrnice I2C.

Rešení 2.1. ˇ | Pomocí nepájivého pole připojte na datový (SDA) a hodinový (SCL) signál sběrnice
I2C moduly pro měření teploty/vlhkosti DHT12 a obvod reálného času DS3231. Pro napájení obou modulů použijte napětí 3.3 V a GND z vývojové desky Arduina.
Ukolem skenovací aplikace je vyslat postupně všechny kombinace adres na I2C (adresa je ´ 7bitová, tj. hodnoty od 0 do 127) a ”poslouchat”, zda-li některý z obvodů na tyto adresy nezareaguje. Využijte příklad z prostředí Arduino IDE, který naleznete v menu File / Examples / Wire / SFRRanger reader a upravte ho do následující podoby.

#include <Wire . h>

void setup ( )
{
Wire . begin ( ) ; | // join i2c bus (address optional for master)
Serial . begin ( 9 6 0 0 ) ; | // start serial communication at 9600 bps
Serial . println ( "---I2C SCANNER ---" ) ;
}

int addr = 0 ;

void loop ( )
{
for ( addr=0; addr <128; addr++) {
Serial . println ( addr ) ;
Wire . requestFrom ( addr , 1 ) ; | // request 1 bytes from slave device #addr
if ( 1 <= Wire . available ( ) ) { | // if one bytes is available for reading
Serial . print ( "...OK...$" ) ;
Serial . println ( addr , HEX ) ;
}
delay ( 1 0 0 ) ;
}

while ( 1 ) {
;
}
}

Dokumentace k jednotlivým funkcím knihovny wire je dostupná na internetových stránkách https://www.arduino.cc/en/Reference/Wire. Aplikaci zkompilujte (Verify), nahrajte do Arduino Uno (Upload) a otevřete monitor sériové asynchronní komunikace, kterou aplikace využívá (Serial Monitor). Pozn.: Ve funkci setup() je nastavena komunikace se symbolovou rychlostí 9 600 Bd; ujistěte se, že konzole sériového monitoru má nastavenou tutéž rychlost.

Z textového výstupu aplikace je patrné, že na sběrnici jsou připojeny celkem tři obvody s I2C adresou. Z internetu, či katalogových listů lze vyčíst, že 0x57 odpovídá sériové paměti EEPROM (umístěné na modulu RTC), 0x5c je kombinovaný teplotní/vlhkostní senzor a adresu 0x68 obsahuje obvod RTC.

86
87
. . . OK . . . $57
88
89
90
91
92
. . . OK . . . $5C
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
. . . OK . . . $68
105
106

Příklad 2.2. Naprogramujte aplikaci komunikující s kombinovaným teplotním a vlhkostním čidlem DHT12.

Rešení 2.2. ˇ | Zapojení aplikace neměňte. Opět můžete vyjít z ukázky File / Examples / Wire
/ SFRRanger reader, kterou upravte pro vyčítání prvních pěti bytů z obvodu DHT12. Pozn.: Z manuálu kombinovaného čidla lze vyčíst, že data jsou v něm uložena dle tabulky 2.1.

Tabulka 2.1: Uložení dat v kombinovaném senzoru DHT12

Adresa | Popis dat
0x00 | Celá část relativní vlhkosti
0x01 | Desetinná část relativní vlhkosti
0x02 | Celá část teploty
0x03 | Desetinná část teploty
0x04 | Kontrolní součet všech dat

#include <Wire . h>

void setup ( )
{
Wire . begin ( ) ; | // join i2c bus (address optional for master)

Serial . begin ( 9 6 0 0 ) ; | // start serial communication at 9600 bps
Serial . println ( "---DHT12 TEST PROGRAM ---" ) ;
}

unsigned char humd = 0 ;
unsigned char temp = 0 ;
float temperature = 0 . 0 ; unsigned char check = 0 ;

void loop ( )
{
Wire . beginTransmission ( 0 x5c ) ; // transmit to temp/humid. device only
Wire . write ( byte ( 0 x00 ) ) ; | // sets register pointer to register 0x00
Wire . endTransmission ( ) ; | // stop transmitting
Wire . requestFrom ( 0 x5c , 5 ) ; | // request 5 bytes from slave device 0x5c
if ( 5 <= Wire . available ( ) ) | // if 5 bytes were received
{
Serial . print ( "Humidity: " ) ;
humd = Wire . read ( ) ; | // read byte from addr. 0x00
Serial . print ( humd ) ; | // display data
Serial . print ( "." ) ;
humd = Wire . read ( ) ; | // read byte from addr. 0x01
Serial . print ( humd ) ; | // display data
Serial . println ( " %RH" ) ;

Serial . print ( "Temperature: " ) ;
temp = Wire . read ( ) ; | // read byte from addr. 0x02
Serial . print ( temp ) ;
Serial . print ( "." ) ;
temperature = ( float ) temp ;
temp = Wire . read ( ) ; | // read byte from addr. 0x03
Serial . print ( temp ) ;
Serial . println ( " deg" ) ;
temperature = temperature + ( ( float ) temp / 1 0 ) ;
Serial . println ( temperature ) ;
check = Wire . read ( ) ; | // read byte from addr. 0x04
Serial . print ( "Checksum: " ) ;
Serial . println ( check , BIN ) ;
Serial . println ( ) ;
}

delay ( 5 0 0 0 ) ;
}

Textový výstup spuštěné aplikace může být následující:

−−−DHT12 TEST PROGRAM−−−
Humidity : 2 5. 7 %RH
Temperature : 2 6. 4 deg
2 6. 4 0
Checksum : 111110

Humidity : 2 5. 2 %RH
Temperature : 2 6. 4 deg
2 6. 4 0
Checksum : 111001

Příklad 2.3. Ověřte komunikační protokol I2C a strukturu jednotlivých rámců pomocí logického analyzátoru.

Rešení 2.3. ˇ | Na sběrnici I2C připojte dva kanály logického analyzátoru Saleae (používaném
v předchozím cvičení) a spust’te vizualizační program Logic na počítači. Zachyt’te komunikaci na sběrnici, nastavte si dekodér I2C v části Analyzers a ověřte posloupnost adresních a datových paketů na sběrnici.

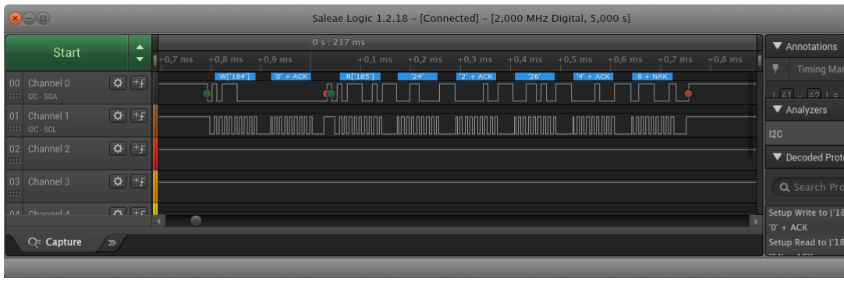
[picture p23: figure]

Obrázek 2.1: Zachycení sériové komunikace na sběrnici I2C

Z obrázku 2.1 je patrné, že datová linka adresuje obvod nejprve pro zápis s následným datovým slovem 0x00 a po opětovném startu komunikace adresuje pro čtení, kdy se vyčte pět datových paketů dle tabulky 2.1.

Příklad 2.4. Naprogramujte aplikaci komunikující s obvodem reálného času DS3231.

Rešení 2.4. ˇ | Aplikaci z bodu 2.2 rozšiřte o funkci komunikující z obvodem RTC (I2C adresa
0x68). Dle manuálu k obvodu DS3231 lze mj. zjistit umístění dat odpovídající sekundám a minutám, viz tabulka 2.2.

Tabulka 2.2: Uložení dat v obvodu reálného času RTC DS3231

Adresa | Bit7 | Bit6 | Bit5 | Bit4 | Bit3 | Bit2 | Bit1 | Bit0 | Popis
0x00 | 0 | Desítky sekund | | | Jednotky sekund | | | | Sekundy
0x01 | 0 | Desítky minut | | | Jednotky minut | | | | Minuty
0x02 | ...

#include <Wire . h>

void setup ( )
{
Wire . begin ( ) ; | // join i2c bus (address optional for master)
Serial . begin ( 9 6 0 0 ) ; | // start serial communication at 9600 bps
Serial . println ( "---TEMP + RTC test ---" ) ;
}

unsigned char temp = 0 ;
float temperature = 0 . 0 ; unsigned char mins10 = 0 ; unsigned char mins1 = 0 ;
unsigned char secs10 = 0 ; unsigned char secs1 = 0 ;

void loop ( )
{
getRTC ( ) ;
getTemp ( ) ;
Serial . println ( ) ;
delay ( 5 0 0 0 ) ;
}

void getRTC ( )
{
Wire . beginTransmission ( 0 x68 ) ; // transmit to rtc device only
Wire . write ( byte ( 0 x00 ) ) ; | // sets register pointer to register 0x00
Wire . endTransmission ( ) ; | // stop transmitting
Wire . requestFrom ( 0 x68 , 2 ) ; | // request 2 bytes from slave device 0x68
if ( 2 <= Wire . available ( ) ) { | // if 2 bytes were received
Serial . print ( "Time: " ) ;
temp = Wire . read ( ) ;
secs10 = temp >> 4 ; | // get 10 Seconds
secs1 = temp & 0x0f ; | // get Seconds
temp = Wire . read ( ) ;
mins10 = temp >> 4 ; | // get 10 Minutes
mins1 = temp & 0x0f ; | // get Minutes

Serial . print ( mins10 ) ;
Serial . print ( mins1 ) ;
Serial . print ( ":" ) ;
Serial . print ( secs10 ) ; Serial . println ( secs1 ) ;
}
}

void getTemp ( )
{
Wire . beginTransmission ( 0 x5c ) ; // transmit to temp/humid. device only
Wire . write ( byte ( 0 x02 ) ) ; | // sets register pointer to register 0x02
Wire . endTransmission ( ) ; | // stop transmitting
Wire . requestFrom ( 0 x5c , 2 ) ; | // request 2 bytes from slave device 0x5c
if ( 2 <= Wire . available ( ) ) { | // if 2 bytes were received
Serial . print ( "Temperature: " ) ;
temp = Wire . read ( ) ;
temperature = ( float ) temp ;
temp = Wire . read ( ) ;
temperature = temperature + ( ( float ) temp / 1 0 ) ; Serial . print ( temperature ) ;
Serial . println ( " deg" ) ;
}
}

Textový výstup aplikace může být následující:

−−−TEMP + RTC test−−−
Time : 3 5: 0 8
Temperature : 2 6. 4 0 deg

Time : 3 5: 1 3
Temperature : 2 6. 4 0 deg

## 3 Komunikace s WiFi modulem

Cílem tohoto cvičení je aplikovat znalosti z předchozích cvičení a vytvořit jednoduchý bod v síti IoT (Internet of Things). Pro bezdrátovou komunikaci je použit WiFi modul ESP8266 ESP-01, dále kombinované teplotní a vlhkostní čidlo DHT12 a pro sběr a vizualizaci dat server https://thingspeak.com/ firmy MathWorks, Inc. Aplikace budou programovány v jazyce C++ v prostředí Arduino IDE. Pro verifikaci správné komunikace s WiFi modulem může být použit logický analyzátor firmy Saleae, Inc.

Příklad 3.1. Naprogramujte aplikaci pro komunikaci s kombinovaným senzorem DHT12.

Rešení 3.1. ˇ | Pomocí nepájivého pole připojte na datový (SDA) a hodinový (SCL) signál sběrnice
I2C modul pro měření teploty/vlhkosti DHT12. Pro napájení modulu použijte napětí 3.3 V a GND z vývojové desky Arduina.
Použijte kód z předešlého cvičení a z opakující se funkce loop() volejte funkce pro měření teploty getTemp() a vlhkosti getHumd(), které naplní čtyři globální proměnné s aktuální teplotou a relativní vlhkostí (vždy celá a desetinná část hodnoty, viz tabulka 2.1).

#include <Wire . h>

void setup ( )
{
Wire . begin ( ) ;
}

unsigned char temp1 = 0 ;
unsigned char temp2 = 0 ;
unsigned char humd1 = 0 ;
unsigned char humd2 = 0 ;

void loop ( )
{
getTemp ( ) ;
getHumd ( ) ;
delay ( 6 0 0 0 0 ) ;
}

void getTemp ( )
{
Wire . beginTransmission ( 0 x5c ) ; // transmit to temp/humid. device only
Wire . write ( byte ( 0 x02 ) ) ; | // sets register pointer to register 0x02
Wire . endTransmission ( ) ; | // stop transmitting
Wire . requestFrom ( 0 x5c , 2 ) ; | // request 2 bytes from slave device 0x5c

if ( 2 <= Wire . available ( ) ) { // if 2 bytes were received
temp1 = Wire . read ( ) ;
temp2 = Wire . read ( ) ;
}
}

void getHumd ( )
{
Wire . beginTransmission ( 0 x5c ) ; // transmit to temp/humid. device only
Wire . write ( byte ( 0 x00 ) ) ; | // sets register pointer to register 0x00
Wire . endTransmission ( ) ; | // stop transmitting

Wire . requestFrom ( 0 x5c , 2 ) ; // request 2 bytes from slave device 0x5c

if ( 2 <= Wire . available ( ) ) { // if 2 bytes were received
humd1 = Wire . read ( ) ;
humd2 = Wire . read ( ) ;
}
}

Senzor komunikuje prostřednictvím dvouvodičové sběrnice I2C. Dokumentace k jednotlivým funkcím knihovny wire je dostupná na internetových stránkách https://www.arduino.cc/en/Reference/Wire (https://www.arduino.cc/en/Reference/Wire) a byly vysvětleny na předchozím cvičení.

Příklad 3.2. Vytvořte účet na serveru pro vizualizaci dat.

Rešení 3.2. ˇ | Postupujte dle následujících pokynů:
1. Na serveru https://thingspeak.com/ vytvořte zdarma účet pomocí tlačítka Get
| Started For Free.
2. Vyplňte své kontaktní údaje a email, který používáte; bude na něj zasláno potvrzení pro
| zřízení účtu.
3. Vytvořte nový komunikační kanál New Channel, vyplňte Name a případný popis
| Description a změňte názvy Field 1 a Field 2 na Temperature a Humidity.
4. Data budou zobrazována v záložce Private View; v záložce API Keys si zkopírujte textový
| řetězec Write API Key, který bude sloužit jako identifikátor vašeho kanálu během WiFi komunikace.

Příklad 3.3. Pomocí WiFi modulu ESP8266 ESP-01 odesílejte data se server.

Rešení 3.3. ˇ | Pomocí nepájivého pole připojte WiFi modul ESP8266 ESP-01 a Arduino Uno dle
obrázku 3.1. Výměna dat mezi modulem a řídicím mikrokontrolérem probíhá prostřednictvím asynchronní komunikace. Všimněte si, že vysílací pin modulu je proto spojen s přijímacím pinem Arduino a obráceně.
ESP8266 ESP-01 | Arduino Uno
U0TXD | Rx (pin 0)
CHIP EN | 3.3V
EXT RSTB | Nepřipojeno
3.3V | 3.3V
GND | GND
GPIO2 | Nepřipojeno
GPIO0 | Nepřipojeno
U0RXD | Tx (pin 1)

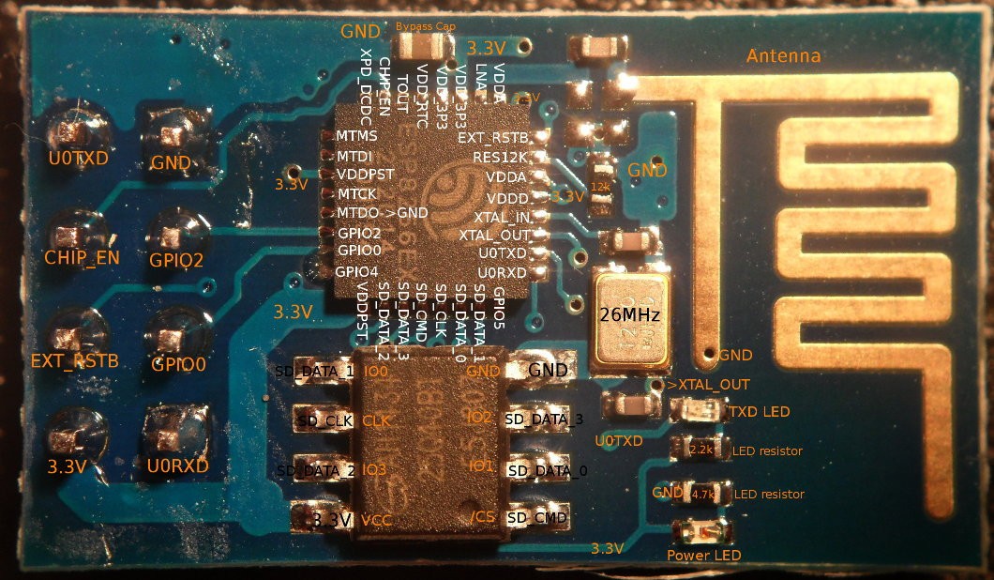
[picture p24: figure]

Obrázek 3.1: Označení pinů na modulu ESP8266 ESP-01

Do zdrojového kódu z příkladu 3.1 přidejte funkce pro konfiguraci WiFi modulu wifi config() a pro opakované posílání dat wifi send().

#include <Wire . h> | // I2C library

String ssid ="xxx" ; | // ssid of your wifi network
String password = "xxx" ; // password of your wifi network String ip_addr = "api.thingspeak.com" ;
String api_key = "xxx" ; // paste your Write API Key here

void setup ( ) {
Wire . begin ( ) ; | // setup I2C communication
Serial . begin ( 1 1 5 2 0 0 ) ; | // setup async. communication with 115200 speed
wifi_config ( ) ; | // setup wifi modul and get ip address from your router
}

unsigned char temp1 = 0 ; // two bytes for temperature
unsigned char temp2 = 0 ;
unsigned char humd1 = 0 ; // two bytes for humidity unsigned char humd2 = 0 ;

void loop ( ) {
getTemp ( ) ; | // get temperature via I2C
getHumd ( ) ; | // get humidity via I2C
wifi_send ( ) ; | // send both values via async. communication
delay ( 6 0 0 0 0 ) ; | // wait for 1 min
}

void getTemp ( )
{
Wire . beginTransmission ( 0 x5c ) ; // transmit to temp/humid. device only
Wire . write ( byte ( 0 x02 ) ) ; | // sets register pointer to register 0x02
Wire . endTransmission ( ) ; | // stop transmitting
Wire . requestFrom ( 0 x5c , 2 ) ; | // request 2 bytes from slave device 0x5c

if ( 2 <= Wire . available ( ) ) { // if 2 bytes were received
temp1 = Wire . read ( ) ;
temp2 = Wire . read ( ) ;
}
}

void getHumd ( )
{
Wire . beginTransmission ( 0 x5c ) ; // transmit to temp/humid. device only
Wire . write ( byte ( 0 x00 ) ) ; | // sets register pointer to register 0x00
Wire . endTransmission ( ) ; | // stop transmitting
Wire . requestFrom ( 0 x5c , 2 ) ; | // request 2 bytes from slave device 0x5c

if ( 2 <= Wire . available ( ) ) { // if 2 bytes were received
humd1 = Wire . read ( ) ;
humd2 = Wire . read ( ) ;
}
}

void wifi_config ( ) {
Serial . println ( "AT" ) ; // test wifi module
delay ( 1 0 0 0 ) ;
Serial . println ( "AT+CWMODE =1" ) ; // set mode to STA
delay ( 2 0 0 0 ) ;
String cmd = "AT+CWJAP =\"" +ssid+"\" ,\"" + password + "\"" ;

Serial . println ( cmd ) ; // login to wifi network and get ip address delay ( 5 0 0 0 ) ;
}

void wifi_send ( ) {
String cmd = "AT+CIPSTART =\" TCP \" ,\"" ;
cmd += ip_addr ;
cmd += "\" ,80" ;
Serial . println ( cmd ) ; | // start comunication with server
delay ( 5 0 0 ) ;
cmd = "GET /update?api_key=" ;
cmd += api_key ; | // prepare request including measured values
cmd += "&field1=" ;
cmd += String ( temp1 ) ; | // include temperature
cmd += "." ;
cmd += String ( temp2 ) ;
cmd += "&field2=" ;
cmd += String ( humd1 ) ; | // include humidity
cmd += "." ;
cmd += String ( humd2 ) ;
cmd += "\r\n" ;
Serial . print ( "AT+CIPSEND=" ) ;
Serial . println ( cmd . length ( ) ) ; // send number of bytes first
delay ( 1 0 0 ) ;
Serial . print ( cmd ) ; | // send request including measured values
}

Vzhledem k tomu, že programování Arduina probíhá na stejných pinech, kde je připojen i WiFi modul, před samotným uploadem kódu odpojte vodiče z pinů 0 a 1 (Rx a Tx). Po úspěšném naprogramování vodiče opět připojte. Spust’te Serial Monitor na kterém pozorujte část komunikace s WiFi modulem (pozor, odpovědi modulu se nezobrazují):

AT
AT+CWMODE=1
AT+CWJAP=”xxx ” , ” xxx”
AT+CIPSTART=”TCP ” , ” api . thingspeak . com ” , 8 0 AT+CIPSEND=62
GET /update ? api_key=xxx&field1=25.0&field2=31.3 AT+CIPSTART=”TCP ” , ” api . thingspeak . com ” , 8 0
AT+CIPSEND=62

Je-li komunikace prostřednictvím WiFi sítě korektní, na webové stránce thingspeak.com se začnou shromažd’ovat a zobrazovat změřená data, viz obrázek 3.2. Pokud tomu tak není, zkontrolujte zda v kódu nemáte chybu, nebo si zobrazte asynchronní komunikaci na pinech 0 a 1 pomocí logického analyzátoru.

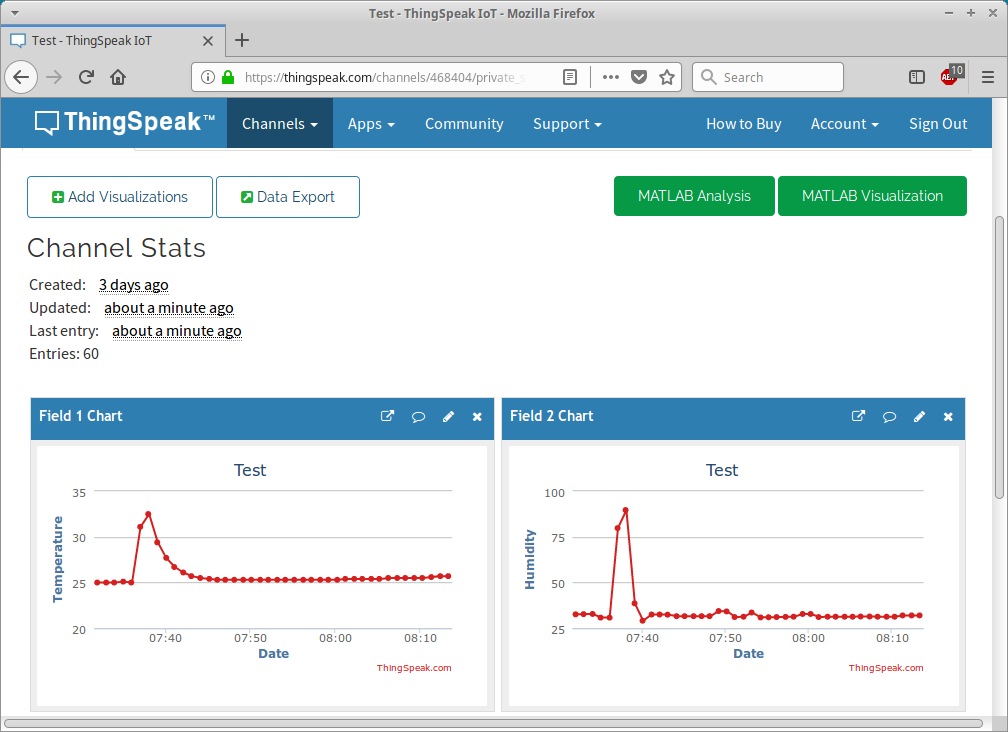
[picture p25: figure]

Obrázek 3.2: Vizualizace měřených dat na serveru https://thingspeak.com/

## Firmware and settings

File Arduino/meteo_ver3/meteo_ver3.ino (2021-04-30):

/***********************************************************************
 * 
 * Arduino Meteo station.
 * Ver. 3: Read values from temperature/humidity sensor DHT12, use 
 *         software UART library for ESP8266 WiFi module and send data 
 *         to ThingSpeak cloud.
 * ATmega328P (Arduino Uno), 16 MHz, Arduino IDE 1.8.13
 *
 * Copyright (c) 2020-Present Tomas Fryza
 * Dept. of Radio Electronics, Brno University of Technology, Czechia
 * This work is licensed under the terms of the MIT license.
 *
 **********************************************************************/

/* Includes ----------------------------------------------------------*/
// Wire library allows you to communicate with I2C/TWI devices
#include <Wire.h>
#include <SoftwareSerial.h>


/* Global variables --------------------------------------------------*/
// Air temperature in the form T0.T1, such as 21.3
unsigned char t0 = 0;
unsigned char t1 = 0;
// Relative humidity in the form H0.H1, such as 25.7
unsigned char h0 = 0;
unsigned char h1 = 0;

// Arduino pin  ESP pin  Arduino point of view
//     2          Tx     Receive data from ESP
//     3          Rx     Transmit data to ESP
SoftwareSerial espSerial(2, 3);

// ENTER YOUR VALUES
String ssid        = "xxx"; // SSID of your WiFi network
String password    = "xxx"; // Password of your WiFi network
String writeApiKey = "xxx"; // Write API Key from ThingSpeak cloud


/* Functions ---------------------------------------------------------*/
/**********************************************************************
 * Function: setup()
 * Purpose:  Setup function where the program execution begins. Init 
 *           serial communications (I2C/TWI, UART) and WiFi module.
 * Returns:  none
 **********************************************************************/
void setup()
{
    // Setup I2C/TWI communication with the Temp/Humid sensor
    Wire.begin();

    // Setup UART communication with Serial monitor in Arduino IDE
    Serial.begin(9600);

    // Setup UART communication with WiFi module
    espSerial.begin(115200);

    // Setup WiFi module and get IP address from your router
    wifiSetup();
}

/**********************************************************************
 * Function: loop()
 * Purpose:  Infinite loop. This function is executed over and over 
 *           again. Ask the temperature/humidity sensor for new data 
 *           and send it to the UART. Use Serial Monitor to view it.
 * Returns:  none
 **********************************************************************/
void loop()
{
    // Ask sensor for new data
    getHumidTempData();

    // Send temperature/relative humidity data to ThingSpeak cloud
    wifiSend();

    // Wait 2 minutes (120,000 milisecs) and then continue
    delay(120000);
}

/**********************************************************************
 * Function: getHumidTempData()
 * Purpose:  Perform I2C/TWI communication with the DHT12 sensor and
 *           request data on humidity (2 bytes) and temperature (2 bytes).
 * Returns:  none
 **********************************************************************/
void getHumidTempData()
{
    // Begin communication with a sensor whose slave address is 0x5c
    Wire.beginTransmission(0x5c);

    // Set the internal address in the sensor to address 0
    Wire.write(byte(0x00));

    // Stop communication
    Wire.endTransmission();

    // Begin communication again and request 4 bytes from slave device
    Wire.requestFrom(0x5c, 4);
    // If 4 bytes were received, store them in global variables
    if (4 <= Wire.available())
    {
        h0 = Wire.read();
        h1 = Wire.read();
        t0 = Wire.read();
        t1 = Wire.read();
    }
}


/**********************************************************************
 * Function: wifiSetup()
 * Purpose:  Get IP address and connect to WiFi network.
 * Returns:  none
 **********************************************************************/
void wifiSetup()
{
    // Test WiFi module
    espData("AT", 1000);

    // Set mode to STA
    espData("AT+CWMODE=1", 2000);

    // Login to WiFi network and get IP address
    espData("AT+CWJAP=\""+ ssid +"\",\""+ password +"\"", 5000);
}


/**********************************************************************
 * Function: wifiSend()
 * Purpose:  Create a GET request and send data to the server.
 * Returns:  none
 **********************************************************************/
void wifiSend()
{
    // Start communication with ThingSpeak server
    espData("AT+CIPSTART=\"TCP\",\"api.thingspeak.com\",80", 1000);

    // Prepare request including temperature/humidity data
    // GET /update?api_key=xxx&field1=21.6&field2=19.4
    String cmd = "GET /update?api_key=";
    cmd = cmd + writeApiKey;
    cmd = cmd + "&field1=";
    cmd = cmd + String(t0);
    cmd = cmd + ".";
    cmd = cmd + String(t1);
    cmd = cmd + "&field2=";
    cmd = cmd + String(h0);
    cmd = cmd + ".";
    cmd = cmd + String(h1);

    // Send number of bytes first. Note that +2 is added for "\r\n"
    espData("AT+CIPSEND=" +String(cmd.length()+2), 100);

    // Send request including temperature/humidity data
    espData(cmd, 100);
}


/**********************************************************************
 * Function: espData()
 * Purpose:  Send AT command to EST8266 module and wait for response.
 * Returns:  response - Response of ESP8266
 **********************************************************************/
String espData(String command, const int timeout)
{
    // Just display info to Serial monitor
    Serial.print("AT Command ==> ");
    Serial.print(command);
    Serial.println("     ");

    // Use software serial and send AT command to ESP8266 module
    String response = "";
    espSerial.println(command);

    // Wait for timeout and read response from receiver pin
    long int time = millis();
    while ((time + timeout) > millis())
    {
        while (espSerial.available())
        {
            char c = espSerial.read();
            response += c;
        }
    }
    return response;
}

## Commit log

2021-02-18 [C] Ver1: Communication with Temp/Humd sensor
2021-02-21 [IMG] I2C screenshots added
2021-03-15 [README] I2C, UART, ESP8266 added
2021-03-15 [IMG] Images for Arduino, I2C, UART added
2021-03-16 [IMG] Fritzing schematics added
    [meteo_ver1.fzz, meteo_ver2.fzz]
2021-03-19 [IMG] UART Serial monitor captured
2021-04-21 [C] I2C-bus scanner created
